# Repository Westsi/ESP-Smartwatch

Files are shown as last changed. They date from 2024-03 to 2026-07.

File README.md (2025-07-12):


# ESP32 Based Smartwatch
A smartwatch with modern features such as notifications and Spotify sync, watch faces that can be customised, a 240x240 round LCD screen, and a companion app connected with a custom BLE profile.

## Features
- Custom BLE Profile allowing for
  - Notification Sync
  - Time Sync
  - Spotify Sync
  - Exercise Sync
- Auto Sleep Timeout to save battery
- Adjustable Brightness
- Semi-customizeable Watch Faces
- Rudimentary Exercise Tracker
- Code for wireless (OTA) updates (most code from [fbiego/ESP32_BLE_OTA_Arduino](https://github.com/fbiego/ESP32_BLE_OTA_Arduino))

## Prototype 1
Prototype 1 Assembly

[Demo Video (youtube.com)](https://www.youtube.com/watch?v=f3tLT5q3JZY)

## TODO
- [ ] Fix OTA updates over BLE
- [ ] Make weather sync as well
- [x] Put it all together
- [ ] Calibrate battery level code
- [ ] Make Exercise Tracker work properly with accelerometer
- [ ] Saveable Preferences

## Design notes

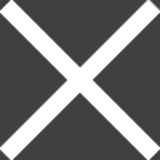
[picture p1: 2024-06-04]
smartwatch_code/images/png/close_160.png

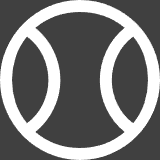
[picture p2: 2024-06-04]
smartwatch_code/images/png/baseball_160.png

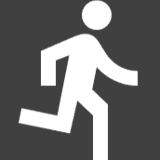
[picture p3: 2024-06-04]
smartwatch_code/images/png/directions_160.png

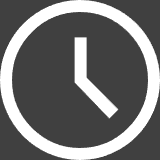
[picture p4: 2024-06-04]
smartwatch_code/images/png/schedule_160.png

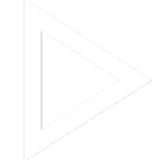
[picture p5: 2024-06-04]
smartwatch_code/images/png/play_160.png

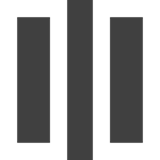
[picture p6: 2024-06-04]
smartwatch_code/images/png/pause_160.png

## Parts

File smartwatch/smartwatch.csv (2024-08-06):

Source: | M:\Custom_Smartwatch\smartwatch\smartwatch.kicad_sch
Date: | 05/08/2024 20:26
Tool: | Eeschema 7.0.5
Generator: | C:\Program Files\KiCad\7.0\bin\scripting\plugins/bom_csv_grouped_by_value_with_fp.py
Component Count: | 35
Ref | Qnty | Value | Cmp name | Footprint | Description | Vendor | DNP
BOOT/FLASH1 | 1 | BOOT/FLASH | SW_Push | Button_Switch_SMD:SW_SPST_Omron_B3FS-100xP | Push button switch, generic, two pins
C1, C4, C8, C13 | 4 | 10nF | C | Capacitor_SMD:C_0805_2012Metric_Pad1.18x1.45mm_HandSolder | Unpolarized capacitor
C2, C3, C9, C10 | 4 | 100nF | C | Capacitor_SMD:C_0805_2012Metric_Pad1.18x1.45mm_HandSolder | Unpolarized capacitor
C5, C7 | 2 | 0.1uF | C | Capacitor_SMD:C_0805_2012Metric_Pad1.18x1.45mm_HandSolder | Unpolarized capacitor
C6 | 1 | 2.2nF | C | Capacitor_SMD:C_0805_2012Metric_Pad1.18x1.45mm_HandSolder | Unpolarized capacitor
C11, C12 | 2 | Polarized_10uF | C_Polarized | Capacitor_Tantalum_SMD:CP_EIA-2012-12_Kemet-R_Pad1.30x1.05mm_HandSolder | Polarized capacitor
GREEN1 | 1 | CHARGED | LED | LED_SMD:LED_0805_2012Metric_Pad1.15x1.40mm_HandSolder | Light emitting diode
J1 | 1 | BAT_CON | Conn_01x02 | Connector_Wire_SMD:Wire_Pad_1x02 | Generic connector, single row, 01x02, script generated (kicad-library-utils/schlib/autogen/connector/)
J2 | 1 | DC_CON | Conn_01x02 | Connector_Wire_SMD:Wire_Pad_1x02 | Generic connector, single row, 01x02, script generated (kicad-library-utils/schlib/autogen/connector/)
J3 | 1 | PROG_INT | Conn_01x02 | Connector_Wire_SMD:Wire_Pad_1x02 | Generic connector, single row, 01x02, script generated (kicad-library-utils/schlib/autogen/connector/)
J4 | 1 | Screen | Conn_01x07 | Connector_Wire_SMD:Wire_Pad_1x07 | Generic connector, single row, 01x07, script generated (kicad-library-utils/schlib/autogen/connector/)
J5 | 1 | Touch | Conn_01x04 | Connector_Wire_SMD:Wire_Pad_1x04 | Generic connector, single row, 01x04, script generated (kicad-library-utils/schlib/autogen/connector/)
J6 | 1 | Power | Conn_01x02 | Connector_Wire_SMD:Wire_Pad_1x02 | Generic connector, single row, 01x02, script generated (kicad-library-utils/schlib/autogen/connector/)
R1 | 1 | 2.2KOhms | R | Resistor_SMD:R_0805_2012Metric_Pad1.20x1.40mm_HandSolder | Resistor
R2, R3 | 2 | 470Ohms | R | Resistor_SMD:R_0805_2012Metric_Pad1.20x1.40mm_HandSolder | Resistor
R4, R5, R6, R7 | 4 | 10KOhms | R | Resistor_SMD:R_0805_2012Metric_Pad1.20x1.40mm_HandSolder | Resistor
RED1 | 1 | CHARGING | LED | LED_SMD:LED_0805_2012Metric_Pad1.15x1.40mm_HandSolder | Light emitting diode
RST1 | 1 | RST | SW_Push | Button_Switch_SMD:SW_SPST_Omron_B3FS-100xP | Push button switch, generic, two pins
SW1 | 1 | SW_Push | SW_Push | Side_Button:Wurth_Elektronik_436331045822 | Push button switch, generic, two pins
U1 | 1 | ESP32-WROVER-E | ESP32-WROVER-E | Espressif:ESP32-WROVER-E | ESP32-WROVER-E and ESP32-WROVER-IE are two powerful, generic WiFi-BT-BLE MCU modules that target a wide variety of applications, ranging from low-power sensor networks to the most demanding tasks, such as voice encoding, music streaming and MP3 decoding. ESP32-WROVER-E comes with a PCB antenna, and ESP32-WROVER-IE with an IPEX antenna. They both featurea 4 MB external SPI flash and an additional 8 MB SPI Pseudo static RAM (PSRAM).
U2 | 1 | MCP73831-5-OT | MCP73831-5-OT | Package_TO_SOT_SMD:SOT-23-5 | Single cell, Li-Ion/Li-Po charge management controller, 4.50V, Tri-State Status Output, in SOT23-5 package
U3 | 1 | MPU-6050 | MPU-6050 | Sensor_Motion:InvenSense_QFN-24_4x4mm_P0.5mm | InvenSense 6-Axis Motion Sensor, Gyroscope, Accelerometer, I2C
U4 | 1 | TLV1117-33 | TLV1117-33 | Package_TO_SOT_SMD:SOT-223-3_TabPin2 | 800mA Low-Dropout Linear Regulator, 3.3V fixed output, TO-220/TO-252/TO-263/SOT-223

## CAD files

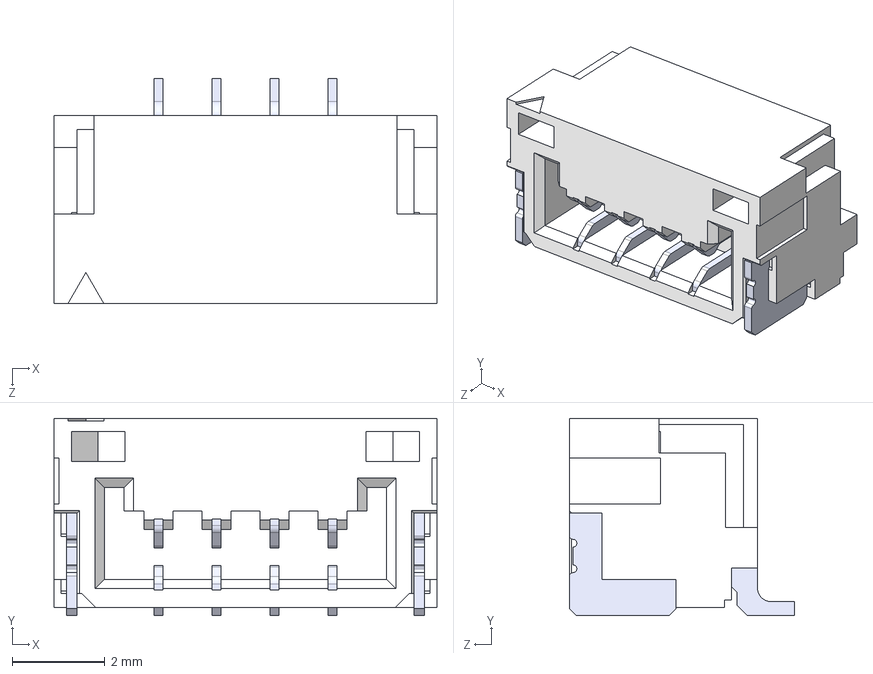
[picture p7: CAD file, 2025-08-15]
smartwatch/SM04B-GHS/SM04B-GHS-TB_LF__SN_-.step
8.25 x 4.25 x 4.85 mm
SMxB-GHS-TB_04
pin x 4

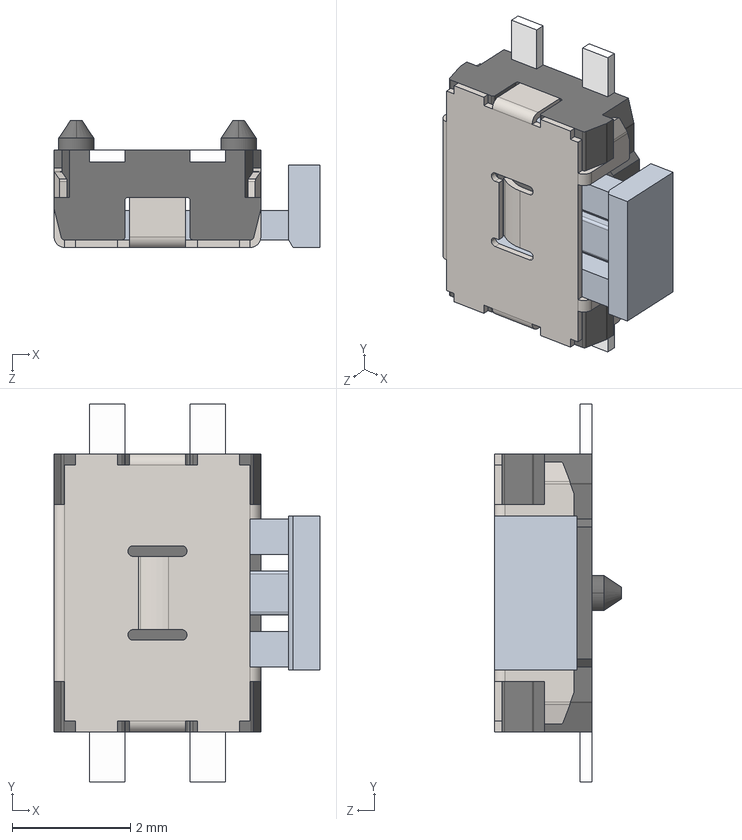
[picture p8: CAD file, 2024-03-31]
smartwatch/436331045822.stp
4.50 x 6.40 x 2.15 mm
frame
pins
pins_3
pins_1
pins_2
stem
cover

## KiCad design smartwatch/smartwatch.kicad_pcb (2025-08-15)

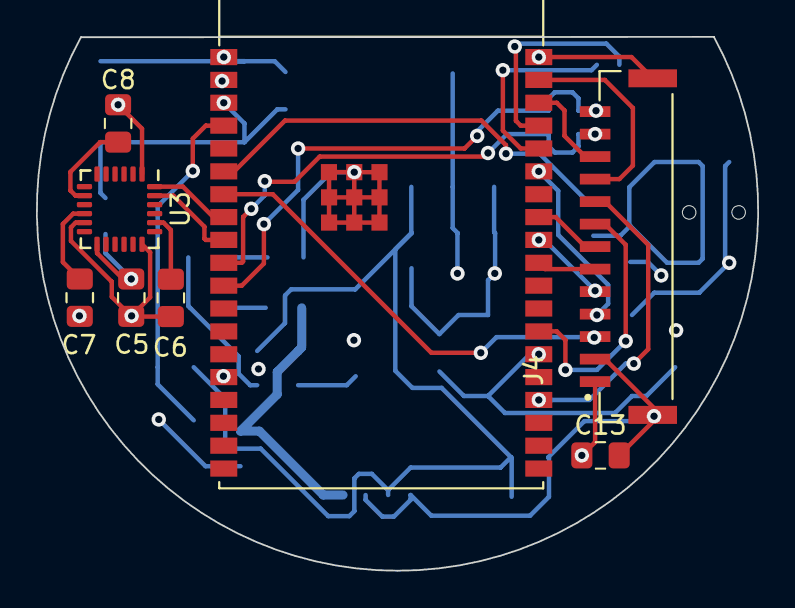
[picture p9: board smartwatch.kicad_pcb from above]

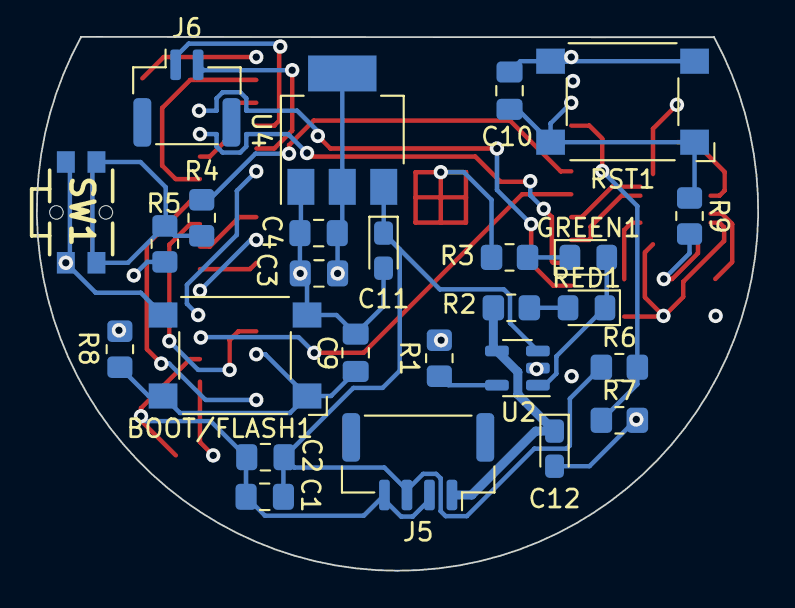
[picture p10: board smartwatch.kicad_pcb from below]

Board: 4 copper layers, 40.1 x 29.7 mm, 34 parts (26 on the bottom side), 31 nets.

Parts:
BOOT/FLASH1: BOOT/FLASH; SW_SPST_Omron_B3FS-100xP
C1, C4, C8, C13: 10nF; C_0805_2012Metric_Pad1.18x1.45mm_HandSolder
C2, C3, C9, C10: 100nF; C_0805_2012Metric_Pad1.18x1.45mm_HandSolder
C5, C7: 0.1uF; C_0805_2012Metric_Pad1.18x1.45mm_HandSolder
C6: 2.2nF; C_0805_2012Metric_Pad1.18x1.45mm_HandSolder
C11, C12: Polarized_10uF; CP_EIA-2012-12_Kemet-R_Pad1.30x1.05mm_HandSolder
GREEN1: CHARGED; LED_0805_2012Metric_Pad1.15x1.40mm_HandSolder
J4: SM13B-GHS-TB; JST_SM13B-GHS-TB
J5: BAT_CON/DC_CON; JST_GH_SM04B-GHS-TB_1x04-1MP_P1.25mm_Horizontal
J6: PROG_INT; JST_GH_SM02B-GHS-TB_1x02-1MP_P1.25mm_Horizontal
R1: 2.2KΩ; R_0805_2012Metric_Pad1.20x1.40mm_HandSolder
R2, R3: 470Ω; R_0805_2012Metric_Pad1.20x1.40mm_HandSolder
R4, R5, R6, R7, R8, R9: 10KΩ; R_0805_2012Metric_Pad1.20x1.40mm_HandSolder
RED1: CHARGING; LED_0805_2012Metric_Pad1.15x1.40mm_HandSolder
RST1: RST; SW_SPST_Omron_B3FS-100xP
SW1: SW_Push; Wurth_Elektronik_436331045822
U1: ESP32-WROVER-E
U2: MCP73831-5-OT; SOT-23-5
U3: MPU-6050; InvenSense_QFN-24_4x4mm_P0.5mm
U4: TLV1117-33; SOT-223-3_TabPin2

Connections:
3V3: C3.2, C4.2, C5.1, C13.1, J4.1, R5.2, R8.1, R9.2, U1.2 (3V3), U3.13 (VDD), U4.2 (VO)
BAT_MEASURE: R6.2, R7.1, U1.4 (SENSOR_VP/GPIO36/ADC1_CH0)
BAT_VDD: C1.2, C2.2, C11.1, J5.3, R6.1, U2.3 (V_{BAT}), U4.3 (VI)
BTN_INP: R4.2, U1.6 (GPIO34/ADC1_CH6)
DC_5V_IN: C12.1, J5.1, R2.1, U2.4 (V_{DD})
DC_GND: BOOT/FLASH1.2, C1.1, C2.1, C3.1, C4.1, C5.2, C6.2, C7.2, C8.2, C9.1, C10.1, C11.2, C12.2, C13.2, J4.2, J4.SH1 (SHIELD), J4.SH2 (SHIELD), J5.2, J5.4, R1.2, R3.2, R7.2, RST1.2, SW1.2, U1.1 (GND), U1.15 (GND), U1.38 (GND), U1.39 (GND_THERMAL), U2.2 (V_{SS}), U3.1 (CLKIN), U3.11 (FSYNC), U3.18 (GND), U4.1 (GND)
EN: C10.2, R9.1, RST1.1, U1.3 (EN/CHIP_PU)
IO0: BOOT/FLASH1.1, C9.2, R8.2, U1.25 (GPIO0/BOOT/ADC2_CH1)
MCP_1: GREEN1.2 (A), RED1.1 (K), U2.1 (STAT)
MPU_SCL: U1.9 (32K_XN/GPIO33/ADC1_CH5), U3.23 (SCL)
MPU_SDA: U1.8 (32K_XP/GPIO32/ADC1_CH4), U3.24 (SDA)
MPU_VLOGIC: C8.1, U3.8 (VLOGIC)
unnamed: GREEN1.1 (K), R3.1
unnamed: R4.1, R5.1, SW1.1
unnamed: R2.2, RED1.2 (A)
unnamed: R1.1, U2.5 (PROG)
unnamed: C6.1, U3.20 (CPOUT)
unnamed: C7.1, U3.10 (REGOUT)
RX: J6.2, U1.34 (U0RXD/GPIO3)
SCR_BL: J4.9, U1.23 (MTDO/GPIO15/ADC2_CH3)
SCR_CS: J4.6, U1.29 (GPIO5)
SCR_DC: J4.7, U1.31 (GPIO19)
SCR_MISO: J4.3, U1.7 (GPIO35/ADC1_CH7)
SCR_MOSI: J4.4, U1.33 (GPIO21)
SCR_RST: J4.8, U1.26 (ADC2_CH0/GPIO4)
SCR_SCLK: J4.5, U1.30 (GPIO18)
TOUCH_IRQ: J4.12, U1.10 (DAC_1/ADC2_CH8/GPIO25)
TOUCH_RST: J4.13, U1.11 (DAC_2/ADC2_CH9/GPIO26)
TOUCH_SCL: J4.11, U1.36 (GPIO22)
TOUCH_SDA: J4.10, U1.37 (GPIO23)
TX: J6.1, U1.35 (U0TXD/GPIO1)

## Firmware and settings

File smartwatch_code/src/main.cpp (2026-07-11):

#include <Arduino.h>

#include "stepcounter.h"
#include "touchscreen.h"
#include "screens/watchface.h"
#include "ble.h"
#include "declarations.h"
#include "notifications.h"
#include "config.h"
#include "updater.h"

void print_system_info();

long phoneupdate = -5000;
long timeupdate = -15000;

void setup() {
    Serial.begin(115200);
    initConfig();
    pinMode(CASE_BUTTON, INPUT);
    pinMode(BATTERY_MEASURE, INPUT);
    // sc_setup();
    bt_setup();
    // initUpdaterFS();
    touch_setup();
    screen_setup();
    // zero notification array
    for (int i=0;i<64;i++) {
        notifications[i] = NULL;
    }
    print_system_info();
}

int pastMode = UPDATER__MODE;

void loop() {
    if (pastMode != UPDATER__MODE && UPDATER__MODE != UPDATER__NORMAL_MODE) {
        screenUpdateInProgressMessage();
    }
    pastMode = UPDATER__MODE;
    switch (UPDATER__MODE) {
        case UPDATER__NORMAL_MODE:
            {
                if (millis() - phoneupdate > 5000) {
                    sendCommand("UPDATE_NOTIFS");
                    phoneupdate = millis();
                }
            
                if (millis() - timeupdate > 18000) {
                    sendCommand("SYNC_TIME");
                    sendCommand("SYNC_SPOTIFY");
                    timeupdate = millis();
                }
                sc_loop();
                bt_loop();
                touch_loop();
                screen_update();
            }
        break;
        case UPDATER__UPDATE_MODE:
            updaterHandleUpdateMode();
            break;
        case UPDATER__OTA_MODE:
            updaterHandleOTAMode();
            break;
    }
    
}

void print_system_info() {
    Serial.printf("CPU Information:\n\t");
    Serial.printf("Revision %d\n\t",  ESP.getChipRevision());
    Serial.printf("Model: %s\n\t", ESP.getChipModel());
    Serial.printf("Cores: %d\n", ESP.getChipCores());

    Serial.printf("Total PSRAM: %d\n", ESP.getPsramSize());
    Serial.printf("Free PSRAM: %d\n", ESP.getFreePsram());
}

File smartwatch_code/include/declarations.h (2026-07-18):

#ifndef DECLARATIONS_H_
#define DECLARATIONS_H_

#define SCREEN_W 240
#define SCREEN_H 240

#define MPU_SDA 32
#define MPU_SCL 33

#define CASE_BUTTON 34

#define BATTERY_MEASURE 36


#define SCREEN_MISO 35
#define SCREEN_MOSI 21
#define SCREEN_CLK 18
#define SCREEN_CS 5
#define SCREEN_DC 19
#define SCREEN_RST 4
#define SCREEN_BL 15

#define TOUCH_SDA 23
#define TOUCH_SCL 22
#define TOUCH_IRQ 25
#define TOUCH_RST 26

#define MANU_NAME "XONIZE_IND"
#define MODEL_NUM "XSW1"
#define FIRMWARE_REV "0.1.0-alpha.1"
#define SOFTWARE_REV "0.1.0-alpha.1"
#define HARDWARE_REV "0.1.0-testing.1"
#define SYSTEM_ID "XSW-DEADBEEF1"

#define TFT_XON_BLUE 0x3535 // #37a4ad
#define TFT_XON_DARK_BLUE 0x3cf4 // #379da8
#define TFT_SPOT_GREEN 0x25ca // #1db954
// https://rgbcolorpicker.com/565


#endif

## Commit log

2024-03-30 finished pcb and sch
    [smartwatch.kicad_pcb, smartwatch.kicad_sch]
2024-03-31 added button
    [436331045822.stp, smartwatch.csv, smartwatch.kicad_pcb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]
2024-04-06 code and some updates
    [smartwatch.kicad_sch]
2024-04-23 couple fixes
2024-05-09 homescreen iffy, custom font not working :/
    [declarations.h, main.cpp, touchscreen.cpp]
2024-05-10 updated pcb schematic and design
    [smartwatch.kicad_pcb, smartwatch.kicad_sch]
2024-05-17 removed unnecessary print statements
2024-05-20 added non animated switch
2024-06-03 changed schematic and pcb of push button connection
    [smartwatch.kicad_pcb, smartwatch.kicad_sch]
2024-06-03 backlight toggling, stepcount ring
    [smartwatch.kicad_pcb, smartwatch.kicad_sch]
2024-06-06 generated gerbers for pcb
    [smartwatch-B_Cu.gbr, smartwatch-B_Mask.gbr, smartwatch-B_Paste.gbr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]
2024-06-09 fully redesigned board - ground and power planes :)
    [smartwatch-B_Cu.gbr, smartwatch-B_Mask.gbr, smartwatch-B_Paste.gbr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]
2024-08-02 implemented battery reading in both code and schem
    [smartwatch.kicad_pcb, smartwatch.kicad_sch]
2024-08-03 battery percentage calculations seem to work
2024-08-07 one way spotify shit and fixed time zones
    [ble.cpp, declarations.h, main.cpp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]
2024-08-09 fixed pcb layout to ensure that wireless module hangs off board
    [smartwatch.kicad_pcb]
2025-01-27 updated gerbers and sent for manufacture
    [smartwatch-B_Cu.gbr, smartwatch-B_Mask.gbr, smartwatch-B_Paste.gbr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]
2025-01-27 enabled DMA? messing around with animations.
2025-04-06 added missing pullups
    [smartwatch.kicad_pcb, smartwatch.kicad_sch]
2025-04-12 fixed crash and updated gradle
    [notifications.cpp, touchscreen.cpp]
2025-05-18 added connector
    [smartwatch.kicad_pcb, smartwatch.kicad_sch]
2025-05-19 finished routing
    [smartwatch.kicad_pcb]
2025-08-15 added connectors for all and reroute
    [SM04B-GHS-TB_LF__SN_-.step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]
2026-03-28 regenerated for prod
    [smartwatch-B_Cu.gbr, smartwatch-B_Mask.gbr, smartwatch-B_Paste.gbr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]
2026-07-12 fixed numbers on analog and stopped notifications being duplicated
    [notifications.cpp]
2026-07-18 super fast sweep and more frames
2026-07-18 fixed a couple bugs and memory leaks
    [notifications.cpp, touchscreen.cpp]
